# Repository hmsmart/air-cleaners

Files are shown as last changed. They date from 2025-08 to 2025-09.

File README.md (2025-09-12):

# Enhanced 3x3 Design
These changes sought to improve the original 3x3 design to reduce plastic use, reduce overall shifting of the parts. This design also allows for the reduction of fans.
## Main Changes
1. Reduced plastic usage.
  * Removed lip sides of box, filter instead rests on ledge around outer walls.
  * Modified mounting brackets to be lower and smaller
2. Improve bonding. Use two attachment points on edges to prevent rotation of box components.
3. Integrate power port. Can cut a specified diameter on the handle center for a power port.
4. Deboss components and orientation for clarity
5. Fan Cutout is controllable in Fan Container to allow for 5x140 fan designs instead of 9x140 fan designs.


## Component weight reductions
For 20x20x1 filter -- Corner pieces are around 130g printed with 3 perimters at 8% infill.

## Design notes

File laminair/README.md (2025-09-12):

# LaminAir V2

Effective personal air cleaning via laminar flow, meant to be used close to the face. In a matter of seconds, can give 5-to-13 exposure reduction factors (i.e. 80-93% reduction of aerosols) when breathing near the middle, 15-inches-or-less away from the face. Another effective tool to add to your arsenal of multilayer protections.

<div style='display: grid; grid-template-columns: 50% 50%; grid-template-rows: auto;'>
    front
    back
    laminair on stand
    laminair on stand at the dentist
    laminair at the dentist
</div>

## Use cases

**Safer dental visits as a patient.**
The LaminAir V2 can be connected to a tripod to so you can breathe in concentrated clean air at the dentist or in the hospital. Get cleaner air wherever you go. LaminAir V2 can boost the protection of the [Readimask Nose hack](https://x.com/findmeabluebird/status/1517896018188197891).

**Safer working in the office.**
Sitting in a cubicle, or working at a desk while wearing a mask? LaminAir V2 can boost the effectiveness of respirators. The effect is multiplicative. For example, if you have a fit tested respirator that has a fit factor of 20, using a LaminAir in conjunction with a mask can gives a combined exposure reduction factor somewhere between 100 (20 x 5) and 260 (20 x 13). In other words, you will be breathing 100 to 260 times lower concentration of aerosols between 0.02 - 1 micron, when combining a mask with a fit factor of 20 with the LaminAir.

**Safer indoor dining.**
Have to eat indoors with a bunch of people? Reduce your risk of getting sick from airborne pathogens and get sick less often using the LaminAir V2.

## Features

**Easily adjustable**: Swivel design lets you easily point the device to your face.

**Versatile**: Can be used with a tripod to get cleaner air at the dentist.

**Rechargeable**: Powerbank included, USB-C rechargeable.

**Modular**: If a part breaks, that part can be easily replaced, without having the need to buy a whole new device.

3D-printed with PETG / PLA plastic.

Designed and Built in the U.S.

## Experimental Results on Efficacy

### Grid of exposure reduction factors
80-92% reduction (5-13 exposure reduction factors) in particles between 0.02 and 1 micron when used close to the face.

Look at a birds-eye view of exposure reduction factors:
exposure reduction factors grid

| label | notes |
| - | - |
|X| corresponds to left and right movement of the head when facing the LaminAir V2. |
|Y| corresponds to moving closer or farther away from the LaminAir.|
|Z| is the height from the ground, kept constant in the middle. |

The graph above was produced by using a PortaCount 8020A. Ambient air was being sampled right in the intake of the device at the back and then compared to the cleaner air in the front:

PortaCount validation

Edderic moved the PortaCount sampling probe inch by inch to get the grid. Each position is a minute's worth of samples. So in total, Edderic spent more than two hours testing the device.

### Using a respirator with and without the LaminAir V2

<table>
<tr>
    <th>Experiment</th>
    <th>Exposure Reduction Factor</th>
</tr>

<tr>
    <td>
        Edderic using an N95 without the LaminAir V2
    </td>
    <td>
        Exposure reduction factor of 14 when only using the N95 with leaks
    </td>
</tr>
<tr>
    <td>Edderic using Makrite 9601 N95</td>
    <td>Edderic getting an exposure reduction factor of 14</td>
</tr>
<tr>
    <td>
        Edderic using an N95 with the LaminAir V2
    </td>
    <td>
        Exposure reduction factor of 14 when using the N95 with leaks + LaminAir V2
    </td>
</tr>
<tr>
    <td>Edderic using Makrite 9601 N95 and LaminAir V2</td>
    <td>Edderic getting an exposure reduction factor of 211</td>
</tr>
</table>

## DIY

If you have access to a 3D printer, and you are interested in printing out the pieces yourself to save on labor, please take a look at [the instructions](./diy/diy.md), which shows the 3D-printable parts in STL format.

If you already have the 3D printed parts and would like to assemble the pieces together, you can also take a look at [the instructions](./diy/diy.md).

The rest of the pieces are listed
[here](https://docs.google.com/spreadsheets/d/1wJ6nfeIdMQBHosVignK3vL9RzcDbh2oNCUtzVA7f1og/edit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), which shows the name of the parts, the amount needed per part, and where you can buy them via Amazon.

## Buying devices

If you'd rather buy a pre-assembled device, you can purchase [here](https://breathesafe-llc.myshopify.com/products/laminair).

### Modifying the pieces

[OpenSCAD](https://openscad.org/) is a tool for programmers to programmatically create 3D-printable designs. See [OpenSCAD tutorials](https://openscad.org/documentation.html) to learn how to use the tool. OpenSCAD lets someone edit `.scad` files. The 3D printable models then get exported from there as STL files, which essentially contain information about shapes and curves. Finally, these STL files are then transformed into G-Code, which contains all the steps for a 3D printer to print the objects. I use [PrusaSlicer](https://www.prusa3d.com/page/prusaslicer_424/) to convert STL files to G-Code. Once that is done, the G-Code is then exported to an SD card, which is then finally inserted to a 3D printer. A fine choice is Prusa's MK3S+.

## License
- [See License](https://github.com/Edderic/air-cleaners/blob/main/LICENSE.md)

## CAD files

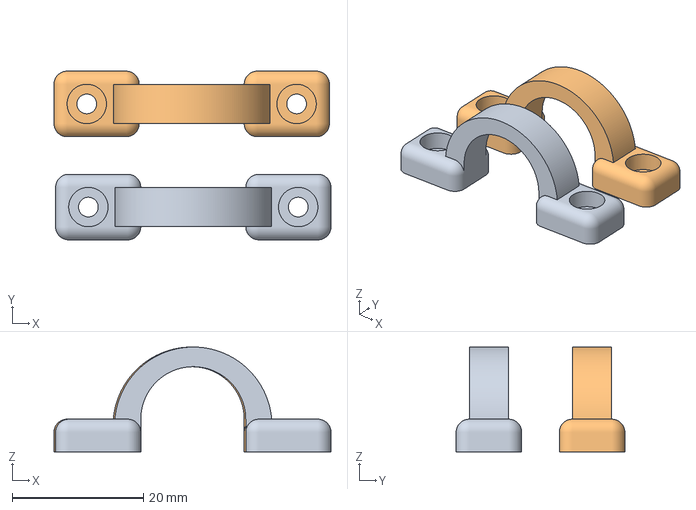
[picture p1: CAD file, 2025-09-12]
common/shoulder_strap_half_ring.3mf
42.2 x 25.7 x 16.0 mm
shoulder_strap_half_ring.stl x 2

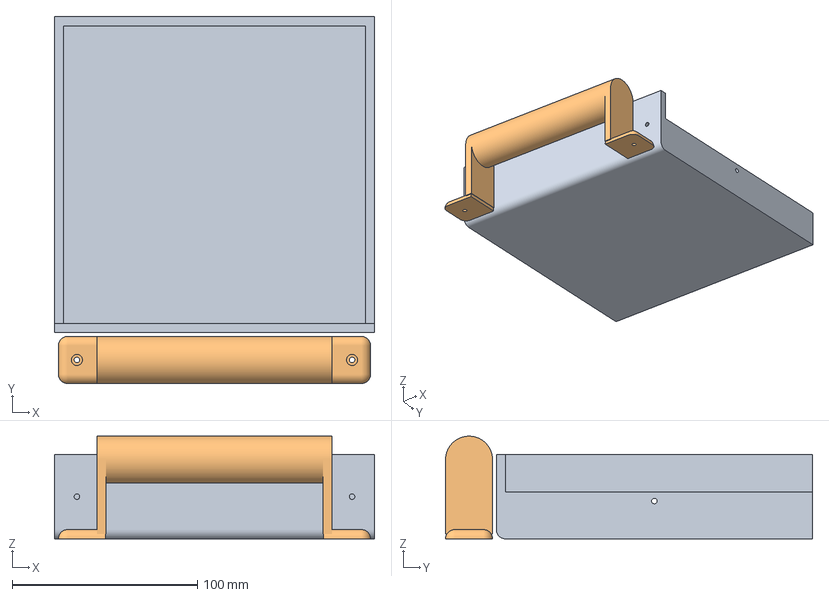
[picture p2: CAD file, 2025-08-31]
cr_boxes/handle.3mf
172.7 x 197.9 x 55.4 mm
top_center.stl
handle.stl

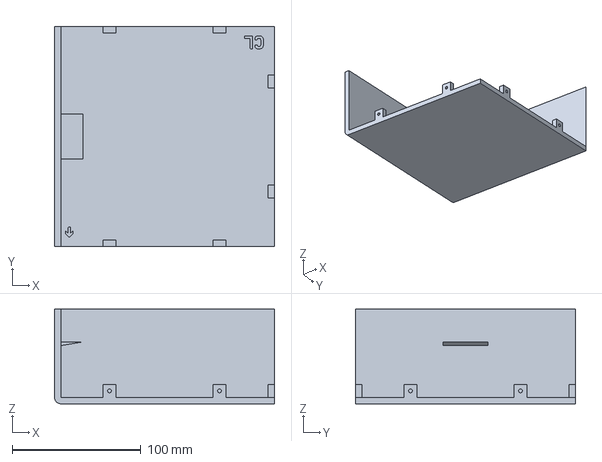
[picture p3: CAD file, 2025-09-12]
cr_boxes/three_by_three/20x20x1_5F/left_center.3mf
170.7 x 170.7 x 73.4 mm

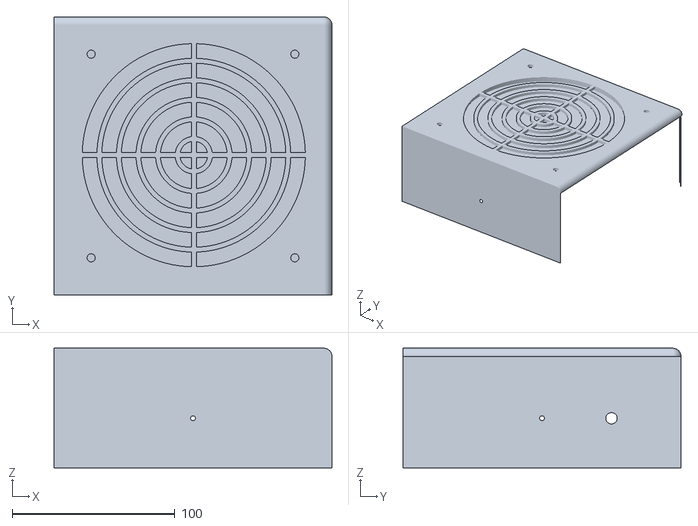
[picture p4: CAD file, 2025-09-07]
cr_boxes/three_by_three/test_center.stl
170.7 x 170.7 x 73.4

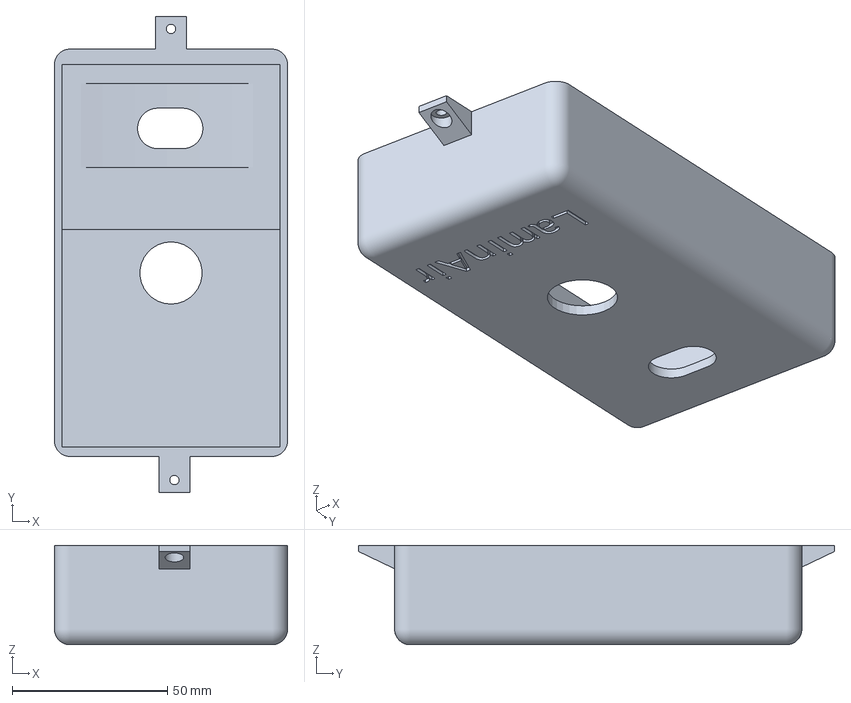
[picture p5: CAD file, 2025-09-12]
laminair/3mf_files/power_switch_mk3s_plus.3mf
75.0 x 153.1 x 32.0 mm

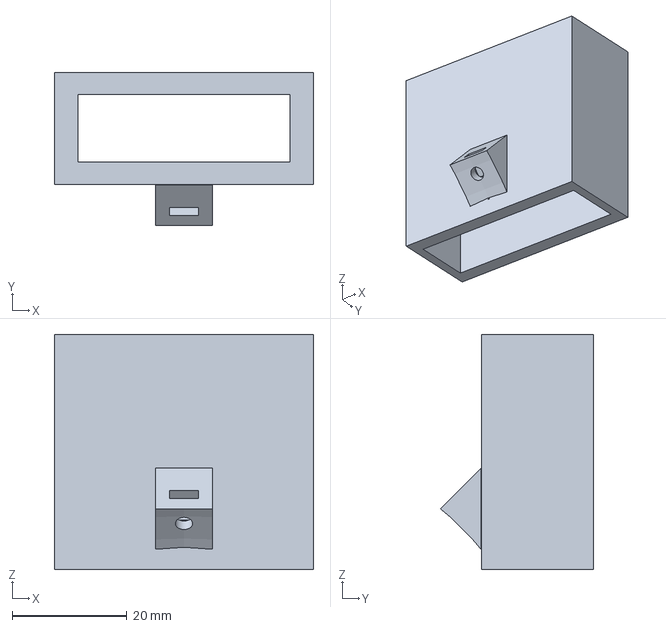
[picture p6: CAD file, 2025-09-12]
misc/sps30_holder_with_wedge.3mf
45.1 x 26.7 x 41.0 mm

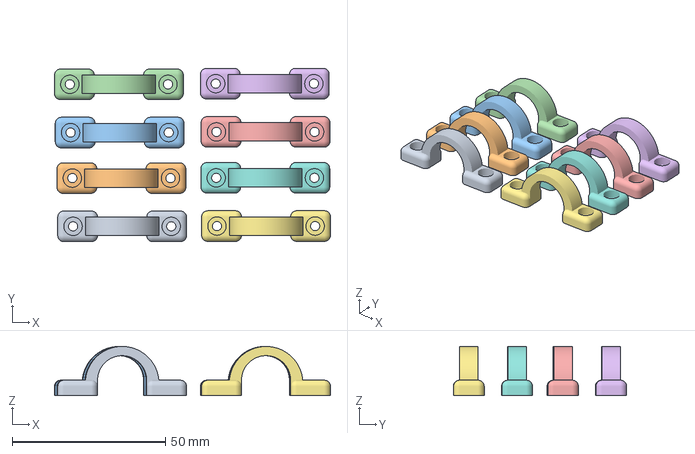
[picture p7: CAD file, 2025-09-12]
common/shoulder_strap_half_ring_4_pairs.3mf
90.0 x 56.5 x 16.0 mm
shoulder_strap_half_ring.stl x 8

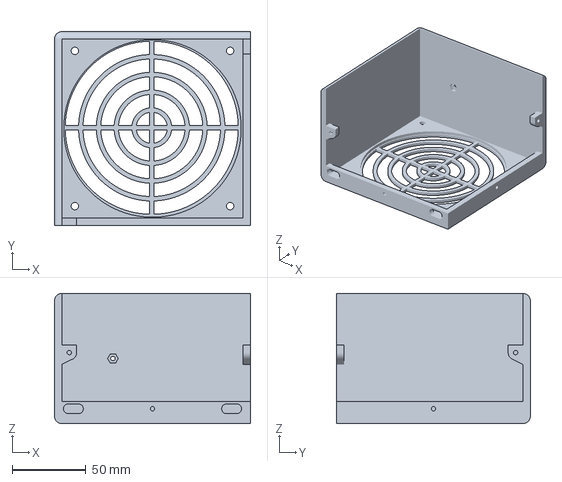
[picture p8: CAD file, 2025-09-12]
laminair/3mf_files/top_right.3mf
132.5 x 131.0 x 88.0 mm

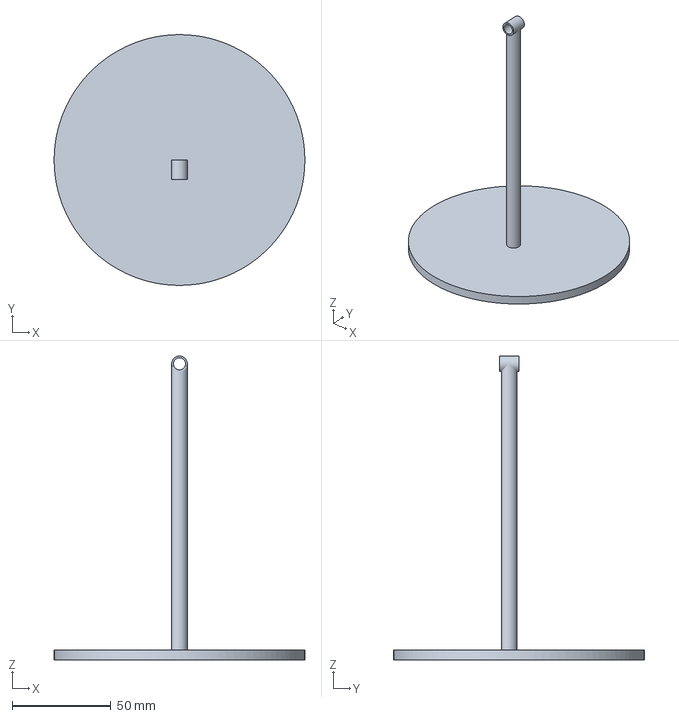
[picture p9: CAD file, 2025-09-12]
misc/probe_stand.3mf
127.0 x 127.0 x 154.0 mm

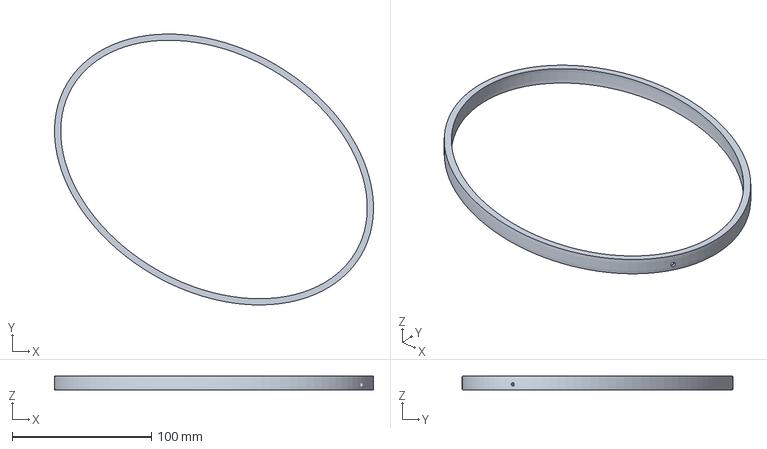
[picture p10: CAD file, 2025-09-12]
misc/head_support.3mf
229.4 x 194.8 x 10.0 mm

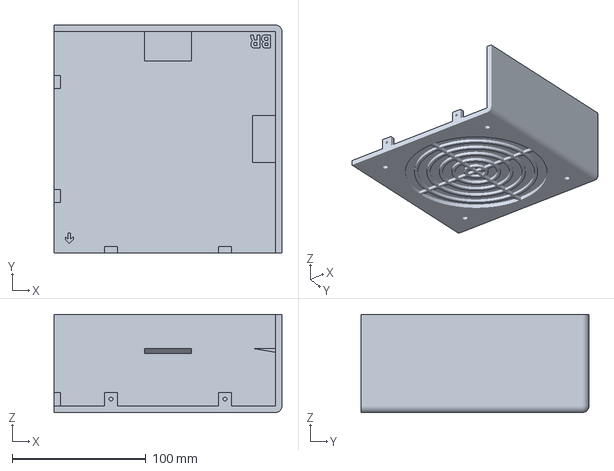
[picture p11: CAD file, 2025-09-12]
cr_boxes/three_by_three/20x20x1_5F/bottom_right.3mf
170.7 x 170.7 x 73.4 mm

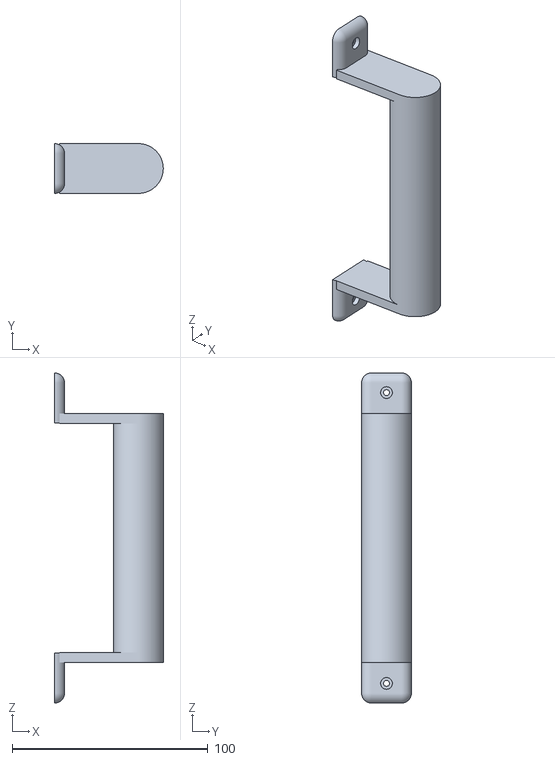
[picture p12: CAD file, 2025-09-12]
cr_boxes/three_by_three/20x20x1_5F/40tall_handle.stl
55.4 x 25.4 x 168.4

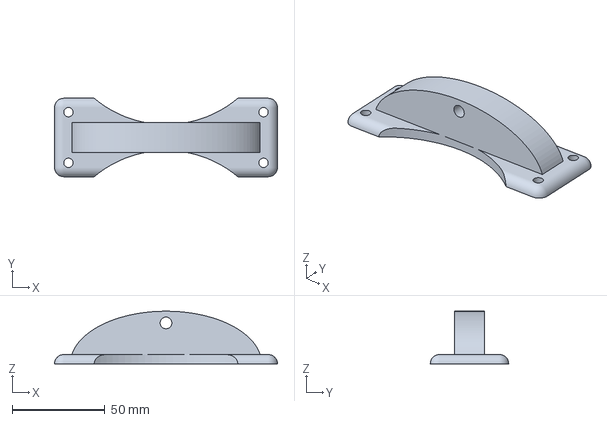
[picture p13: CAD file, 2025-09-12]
laminair/3mf_files/elbow_mk3s_plus.3mf
120.0 x 42.2 x 28.3 mm

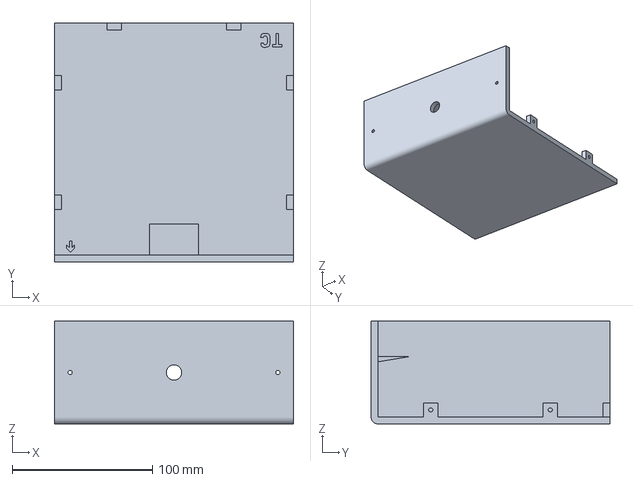
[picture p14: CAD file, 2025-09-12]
cr_boxes/three_by_three/20x20x1_5F/center_top.3mf
170.7 x 170.7 x 73.4 mm

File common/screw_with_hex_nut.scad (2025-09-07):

use <screw.scad>
use <hex_nut.scad>

module screw_with_hex_nut(hex_nut_height=2, screw_head_height=3, threaded_height=10, threaded_radius=1.5, screw_head_radius=3, hex_nut_side_length=2.9) {
  screw(screw_head_radius=screw_head_radius, screw_head_height=screw_head_height, threaded_radius=threaded_radius, threaded_height=threaded_height);

  translate([0,0, screw_head_height + threaded_height - hex_nut_height]) {
    hex_nut(side_length=hex_nut_side_length, height=hex_nut_height);
  }
}

screw_with_hex_nut();

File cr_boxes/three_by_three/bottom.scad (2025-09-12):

use <fan_container.scad>

filter_z = get_filter_dim()[2];
grid_z = get_grid_z();
W = get_width();
L = get_length();
D = get_depth();

ofsX   = W/4;                 // 1/4 and 3/4 along TOP/BOTTOM (X)
ofsY   = L/4;                 // 1/4 and 3/4 along LEFT/RIGHT (Y)
z_drill = filter_z + grid_z - 10;

difference(){
    union(){
        fan_container(
          filter_z=filter_z,
          z=grid_z,
          top_left_corner_smoothed=false,
          bottom_left_corner_smoothed=false,
          bottom_right_corner_smoothed=false,
          top_right_corner_smoothed=false,
          edge_fan_top_smoothed=false,
          edge_fan_bottom_smoothed=true,
          edge_fan_right_smoothed=false,
          edge_fan_left_smoothed=false,
          edge_top_left_smoothed=false,
          edge_top_right_smoothed=false,
          edge_bottom_left_smoothed=false,
          edge_bottom_right_smoothed=false,
          top_screw_hole=false,
          left_screw_hole=false,
          bottom_screw_hole=false,
          right_screw_hole=false,
          long_wall="bottom",
          fan_hole=false,  
          left_wire_route_hole=false,
          right_wire_route_hole=false,
          top_wire_route_hole=false,
          bottom_wire_route_hole=false
         );
        // TOP
        for (a=[-ofsX, ofsX]) difference() {
          edge_nub_cube("top", a, nub_len=10, nub_proj=D, nub_h=10);
          edge_screw_cut(edge="top", at=a, z_drill=z_drill, nub_proj=D);
        }

        // LEFT (Y = ±ofsY)
        for (a=[-ofsY, ofsY]) difference() {
          edge_nub_cube("left", a, nub_len=10, nub_proj=D, nub_h=10);
          edge_screw_cut(edge="left", at=a, z_drill=z_drill, nub_proj=D);
        }

        // RIGHT
        for (a=[-ofsY, ofsY]) difference() {
          edge_nub_cube("right", a, nub_len=10, nub_proj=D, nub_h=10);
          edge_screw_cut(edge="right", at=a, z_drill=z_drill, nub_proj=D);
        }
        //Tabs
        place_tabs("bottom",  W, L-(D*2), D, filter_z, count=1);
     };
     bottom_labels(
        width=get_width(),
        length=get_length(),
        bottom_z=filter_z+grid_z-get_depth()+.8,
        part_code="BC",
        top_T_size=10,
        part_size=10,
        edge_margin=get_depth()*1.5
     );
}

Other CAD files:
cr_boxes/three_by_three/20x20x1_5F/bottom_center.3mf
cr_boxes/three_by_three/20x20x1_5F/center_center.stl
laminair/3mf_files/bottom_right_mk3s_plus.3mf
laminair/3mf_files/top_left.3mf
cr_boxes/three_by_three/bottom_left.scad
cr_boxes/three_by_three/bottom_right.scad
common/cone.scad
common/fan.scad
common/flexible_handle.scad
common/hex_nut.scad
common/noctua_speed_controller.scad
common/nut.scad
common/screw.scad
common/screw_with_nut.scad
common/shoulder_strap_half_ring.scad
common/shoulder_strap_half_ring.stl
common/shoulder_strap_support_screws.scad
common/smoothed_corner.scad
common/smoothed_cube.scad
common/smoothed_edge.scad
common/switch.scad
common/tcore_powerbank.scad
common/usbc_female.scad
cr_boxes/three_by_three/20x20x1_5F/69tall_handle.stl
cr_boxes/three_by_three/20x20x1_5F/bottom_left.3mf
cr_boxes/three_by_three/20x20x1_5F/bottom_left.stl
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

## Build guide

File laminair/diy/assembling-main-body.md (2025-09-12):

# DIY

## Assembling the main body

### What's needed

| Item | Amount | Link | Notes |
| - | - | - |- |
| M3x8mm hex head screw | 8 | [link](https://www.amazon.com/gp/product/B01MCW5GM3/ref=ewc_pr_img_1?smid=A30WUG2ZDGM0XM&psc=1) |
| M3x8mm hex nut | 8 |  [link](https://www.amazon.com/gp/product/B08N68W9SP/ref=ppx_yo_dt_b_search_asin_title?ie=UTF8&th=1) |
| top_left.stl | 1 | [link](./laminair/top_left.stl) |
| top_right.stl | 1 | [link](./laminair/top_right.stl) |
| bottom_left.stl | 1 | [link](./laminair/bottom_left.stl) |
| bottom_right.stl | 1 | [link](./laminair/bottom_right.stl) |

Arrange the 4 main parts like so:


There should be two holes in red. That will be used for the handle later on. Also notice the two blue holes on the right. Those will be used for the container for the power bank & power switch.

Using an **M3x8mm hex screw**, screw the top left and bottom left pieces together.



Before going all the way, make sure to add the **M3 nut** at the bottom. Continue screwing until the two feel secure.



Do the same thing for this section next:



Next, we work on connecting the bottom pieces togetherc



Insert the **M3 hex nut** before fully tightening:



The power switch has a **male** end and a **female** end. The **female** end should be in the main body, while the **male** end along with the **power switch** should be outside the main body. Insert the wire between the **female** end and the power switch into the groove of the bottom right part:



A more close-up view:



Complete the main body:



Use **M3x8mm** screws and nuts to secure the main body:







[Go back to DIY page](./diy.md)
[Next up: Installing the handle](./installing-the-handle.md)

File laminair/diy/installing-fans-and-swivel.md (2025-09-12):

# DIY

## Installing the fans and swivel

### What's needed

| Item | Amount | Link |
| - | - | - |
| Assembled main body with handle from the previous step | 1 | [link](./installing-the-handle.md) |
| M4x35mm screws | 12 | [link](https://www.amazon.com/cSeao-M4x35mm-Machine-Phillips-Stainless/dp/B08R8K2QSW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) |
| M4x40mm screws | 4 | [link](https://www.amazon.com/gp/product/B06Y1YCSB8/ref=ppx_yo_dt_b_search_asin_title?ie=UTF8&psc=1) |
| M4 nylon insert lock nuts | 16 | [link](https://www.amazon.com/M4-0-7-Nylon-Insert-Stainless-100pcs/dp/B0BHQMBRFX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) |
| Philips Screw Driver | 1 |  [link](https://www.amazon.com/Screwdriver-Industrial-Strength-Klein-Tools/dp/B0015SBILG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) |
| Needle-nose Pliers | 1 |  [link](https://www.amazon.com/CRAFTSMAN-CMHT81645-Long-Nose-Pliers/dp/B08PFK8YWQ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) |
| ARCTIC P12 120mm fans| 4 |  [link](https://www.amazon.com/dp/B07HC782D5?ref=ppx_yo2ov_dt_b_product_details&th=1) |
| CRJ Full Speed 12V Voltage Step-Up USB to 3-Pin and 4-Pin PC Fan Sleeved Power Adapter Cable | 1 |  [link](https://www.amazon.com/dp/B07QFG6LFR?psc=1&ref=ppx_yo2ov_dt_b_product_details) |

### Steps

Insert a **120mm fan** to the bottom left section like so:


Insert a **M4x35mm** screw into the holes **farthest away from the center of the main body**:



Screw in the **M4 lock nut**:


Use the **needle-nose pliers** to hold the **M4 lock nut** in place while you screw:


Repeat the same steps for the other screw hole, and then insert the other bottom fan:


Repeat the screwing procedure with the **M4x40mm screws** and **M4 lock nuts**.



Have the main body have the intake section be facing up. Place the swivel on top of the bottom layer of fan containers, and line up the screw holes with the bottom:



Using **M4x40mm** screws, secure the **swivel** to the main body:


Flip the LaminAir over, add the **M4 lock nuts**, then tightend them using the **needle-nose pliers** and the **philips screw driver**:


Insert the other 2 fans, and secure them to the **main body** via 8 **M4x35mm** screws and 8 **M4 lock nuts**.


Get the **CRJ 12V USB-to-4-pin**. Connect the USB male end of that to the female end of the **ELECTOP power switch**:


Daisy chain the fans to each other, and have one of the fans connect to the **CRJ 12V USB-to-4-pin**:


Use velcro or cable ties to tidy up the wiring:



[Go back to DIY page](./diy.md)
[Next up: Installing the power bank](./installing-power-bank.md)

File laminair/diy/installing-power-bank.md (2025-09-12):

# DIY

## Installing the power bank

### What's needed

| Item | Amount | Link |
| - | - | - |
| Assembled main body with handle and fans from the previous step | 1 | [link](./installing-fans-and-swivel.md) |
| power_switch.stl| 1 | [link](./power_switch.stl) |
| M3x8mm hex head screw | 2 | [link](https://www.amazon.com/gp/product/B01MCW5GM3/ref=ewc_pr_img_1?smid=A30WUG2ZDGM0XM&psc=1) |
| M3x8mm hex nut | 2 |  [link](https://www.amazon.com/gp/product/B08N68W9SP/ref=ppx_yo_dt_b_search_asin_title?ie=UTF8&th=1) |
| UseBean Right Angle USB C Extension Cable | 1 |  [link](https://www.amazon.com/gp/product/B08F7BSG24/ref=ppx_yo_dt_b_search_asin_title?ie=UTF8&psc=1) |
| 2.5mm hex wrench | 1 |  [link](https://www.amazon.com/HORUSDY-Wrench-Metric-30-Piece-0-7mm-10mm/dp/B075BZGJJK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) |

### Steps

Get the `power_switch`:


Using the **2.5mm hex wrench**, make sure the holes for the screws are not obstructed:



Get the the **UseBean Right Angle USB C Extension Cable**.

Screw in the **M4 lock nut**:


Insert the wider USB-C end into the top hole. It will be tight. Wiggle it in to make room for it.




Remove the USB-C end from the power switch container, and then insert the power switch into the corresponding hole:


Insert the wider USB-C end into the top hole again, while the power switch is in the correct position:


Get the power bank:



Plug the USB male of the power switch into the power bank:


Remove the plastic from the other end of the **USB C extension cable**:


Connect the other end of the **USB C extension cable** into the power bank, like so:


Reposition:


Add **M3x8mm** screws to the top and bottom screw holes:



Connect the power bank container to the main body. Screw to tighten, while also
adding **M3 hex nuts** for a more secure connection.


Tighten:


[Go back to DIY page](./diy.md)
[Next up: Installing the stand](./installing-stand.md)

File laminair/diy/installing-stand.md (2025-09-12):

# DIY

## Installing the stand

### What's needed

| Item | Amount | Link |
| - | - | - |
| Assembled main body with handle, fans, power bank from the previous step | 1 | [link](./installing-power-bank.md) |
| stand.stl| 1 | [link](./stand.stl) |
| flange nuts| 2 | [link](https://www.amazon.com/gp/product/B00L1LBFPQ/ref=ppx_yo_dt_b_search_asin_title?ie=UTF8&psc=1) |
| M3x8mm hex nut | 2 |  [link](https://www.amazon.com/gp/product/B08N68W9SP/ref=ppx_yo_dt_b_search_asin_title?ie=UTF8&th=1) |
| 4-point stud knobs | 1 |  [link](https://www.amazon.com/dp/B091DQ53BJ?ref=ppx_yo2ov_dt_b_fed_asin_title) |

### Steps

Get the relevant materials:


Turn the main body so that you could see the hole for the swivel is pointing up.  Align the holes:


Start screwing in the stud knob from the other side. Stop when the screw part of the stud knob is about to come out:


Add the **flange nut**:


Using your thumb, hold down the **flange nut** while tigtening via the **stud knob**.


Other side should look something like this:


[Go back to DIY page](./diy.md)
[Next up: Installing the filters](./installing-filters.md)

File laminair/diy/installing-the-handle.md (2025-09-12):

# DIY

## Installing the handle

### What's needed

| Item | Amount | Link | Notes |
| - | - | - |- |
| Assembled main body from the previous step | 1 | [link](./assembling-main-body.md) |
| M3x8mm hex head screw | 2 | [link](https://www.amazon.com/gp/product/B01MCW5GM3/ref=ewc_pr_img_1?smid=A30WUG2ZDGM0XM&psc=1) |
| M3x8mm hex nut | 2 |  [link](https://www.amazon.com/gp/product/B08N68W9SP/ref=ppx_yo_dt_b_search_asin_title?ie=UTF8&th=1) |
| Reliable Hardware Company RH-0570BK-2-A Strap Handle Set | 1 |  [link](https://www.amazon.com/dp/B00JJ190AW?ref=ppx_yo2ov_dt_b_product_details&th=1) |
| Washer | 2 |  [link](https://www.amazon.com/dp/B00JJ190AW?ref=ppx_yo2ov_dt_b_product_details&th=1) |

### Steps

Set the main body so the two holes for the straps are at the top:


Place the **handle** on the top of the main body:


Place a **washer** near one of the two holes:


Using the **M3 hex wrench**, wiggle the **washer** so that it's in between the rubber and the metal part:



Insert the **M3x8mm hex screw** and start screwing it in:


When half-way done, insert the **M3 hex nut** on the other side:


Screw as tight as possible:


Now do the same steps for the other side:


You will have to push the loose end of the handle to make a curve so that the screw is perpendicular to the main body.This might be a little challenging. You will have to hold this position while also screwing the **M3x8mm** screw:



Add the **M3 hex** to the remaining hole and then continue screwing to tighten the connection between the handle and the main body:


Tighten as much as possible:


[Go back to DIY page](./diy.md)
[Next up: Installing the fans and the swivel](./installing-fans-and-swivel.md)

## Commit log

2025-08-30 Fix Screw Placement
    [center.scad, fan_container.scad, top.scad]
2025-08-31 Generate 20x20x1 5 fan models
    [bottom.scad, bottom_center.3mf, bottom_center.stl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]
2025-09-02 Add top mount barrel plug option, raise main walls to support P14 and lower profile filter
    [fan_container.scad, top.scad]
2025-09-02 wire routing add
    [fan_container.scad, top.scad]
2025-09-03 Deboss orientation and part on inner surfaces
    [fan_container.scad, top.scad, top_center.stl]
2025-09-07 Optimizing design for more efficient use of filament
    [bottom.scad, bottom_center.3mf, bottom_center.stl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]
2025-09-07 Lock Top Code
    [fan_container.scad, top.scad]
2025-09-12 threeby - 202005x5fans
    [40tall_handle.stl, 69tall_handle.stl, LaminAir - v2 fit factor grid.csv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]
2025-09-12 fix some weird tracking issue
    [LaminAir - v2 fit factor grid.csv, bottom_left.3mf, bottom_left.scad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]
